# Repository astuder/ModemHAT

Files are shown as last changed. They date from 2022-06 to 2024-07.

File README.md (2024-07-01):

# Modem HAT for the Raspberry Pi

This HAT is a modem that connects the Raspberry Pi to a plain old analog telephone line.

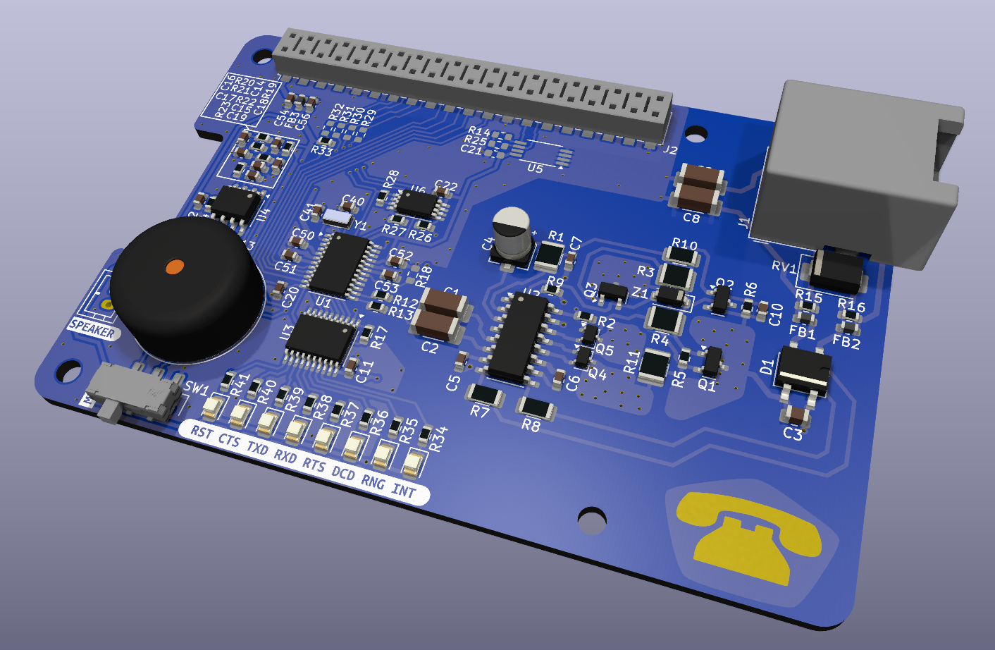
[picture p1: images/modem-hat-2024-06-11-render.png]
Render of Modem HAT


The modem presents itself to the Raspberry Pi on an UART and is controlled with the classic AT command set. It supports various standards (V.22bis, V.32bis, V.34, V.90, ...) at speeds of up to 56 kbps.

The design is based on a [Skyworks ISOmodem](https://www.skyworksinc.com/en/Products/Modems-and-DAAs/Data-and-Voice-Modems) chipset, specifically [Si2457](https://www.skyworksinc.com/en/Products/Modems-and-DAAs/Data-and-Voice-Modems/Si2457) data modem and Si3018 line side driver. The implementation
closely follows the circuits described in application note [AN93](https://www.skyworksinc.com/-/media/SkyWorks/SL/documents/public/application-notes/AN93.pdf).

The Modem HAT was successfully tested on the [Shadytel](https://shady.tel/) phone network at Toorcamp 2022.

> [!CAUTION]
> Whatever your jurisdiction, we're pretty positive that connecting this device to the public phone system IS NOT LEGAL! Don't blame us if you get into trouble.

## Raspberry Pi Configuration

> [!NOTE]
> This information was tested on Raspberry Pi 4 and Raspberry 5, running Raspberry Pi OS 12 (Bookworm). There may be differences for other versions of the Pi and/or Pi OS.

The modem HAT requires a Raspberry Pi 4 or newer.

The modem communicates through the Pi's UART on GPIO 8-11, and requires CTS and RTS for flow control. The modem supports automatic baudrate detection at speeds up to 307.2 kps.

Before first use after power-up, the modem needs to be reset. To reset the modem, GPIO25 (pin 22) is set low for at least 500ms, then set high, followed by a delay of at least 300ms. 

By default, the modem is configured for operation in the United States. For other countries the modem may have to be reconfigured after reset. See [AN93](https://www.skyworksinc.com/-/media/SkyWorks/SL/documents/public/application-notes/AN93.pdf) chapter 6.2 for details. 

Below are the configuration steps for Raspberry Pi 4 and Raspberry Pi 5.

### Raspberry Pi 4

To enable the UART, edit `/boot/firmware/config.txt` and add the following line at the end of the file:

`dtoverlay=uart4,ctsrts`

After rebooting the Raspberry Pi, the UART is mapped to `/dev/ttyAMA4`.

To reset the modem, run the Python script [`reset-pi4.py`](python/reset-pi4.py).

The modem is now ready to use. For example connect to the modem by running:

`screen /dev/ttyAMA4 115200`

Once connected to the modem, if you type `at` and press enter, the modem should respond with `OK`.

### Raspberry Pi 5

To enable the UART, edit `/boot/firmware/config.txt` and add the following line at the end of the file:

`dtoverlay=uart3-pi5,ctsrts`

After rebooting the Raspberry Pi, the UART is mapped to `/dev/ttyAMA3`.

To reset the modem, run the Python script [`reset-pi5.py`](python/reset-pi5.py).

The modem is now ready to use. For example connect to the modem by running:

`screen /dev/ttyAMA3 115200`

Once connected to the modem, if you type `at` and press enter, the modem should respond with `OK`.

## AT Command Set

The modem supports the [basic Hayes command set](https://en.wikipedia.org/wiki/Hayes_command_set#The_basic_Hayes_command_set).

For a complete list of supported AT commands as well as configuration registers refer to [AN93](https://www.skyworksinc.com/-/media/SkyWorks/SL/documents/public/application-notes/AN93.pdf) chapters 5.4 through 5.7. 

## Raspberry Pi GPIO Pinout

Required connections:
|Pin|Description|
|-|-|
|1|3.3V power for modem chipset|
|2,4|5V power for audio amplifier|
|6|GND|
|19|UART CTS|
|21|UART RX|
|22|Modem reset, RPi GPIO25|
|23|UART RTS|
|24|UART TX|

Optional connections:
|Pin|Description|
|-|-|
|13|Modem interrupt, RPi GPIO27|
|15|Modem boot config EEPROM SDIO, RPi GPIO22|
|16|Modem boot config EEPROM CS, RPi GPIO23|
|18|Modem boot config EEPROM CLK, Rpi GPIO24|
|27|RPi config EEPROM SDA|
|28|RPi config EEPROM SCL|

In the standard configuration of the HAT, the modem boot config and interrupt pins are not electrically connected to the Rasbperry Pi GPIO header. Populate R29-R32 with 0-ohm resistors to use these pins.

## Building Your Own HAT

### General

Large parts of the HAT are based on the hardware design reference in application note [AN93](https://www.skyworksinc.com/-/media/SkyWorks/SL/documents/public/application-notes/AN93.pdf) chapter 4. Where applicable, identical component designators are used to simplify cross-referencing. 

I used solder paste, stencil and reflow oven for assembly of the HAT. I also ordered partially assembled boards from JLCPCB, and manually soldered the parts that they didn't have in stock (modem chipset and high-voltage capacitors).

After soldering the through-hole parts (RJ11 connector, speaker), make sure to clip the leads on the bottom side of the HAT to avoid shorting with metal parts on the Raspberry Pi.

### Modem

The modem chipset consists of the digital part Si2457 (U1) and analog part Si3018 (U2).

These are expensive parts, costing US $13-$16 and $6-$8 respectively when purchased from reputable distributors. While tempting, beware of sources like Ebay and AliExpress as parts may be salvaged, old or even fake. It will be much easier to diagnose problems without having to second guess whether the core components of the HAT are genuine.

The HAT uses a 32.768 kHz crystal (Y1) to clock the Si2457, mainly chosen for small size and because I already had a few in my parts bin. The downside of this choice are the slow reset sequence (800 ms) and that this clocking option is only supported by Si2457 revision D (part number SI2457-D-FT) or newer.

If you suspect that you're stuck with an old part, you could try using a 4.9152 MHz crystal instead. In that case you must remove R17 which configures the clock speed. You may also have to replace the load capacitors (C40, C41) with appropriate values. See [AN93](https://www.skyworksinc.com/-/media/SkyWorks/SL/documents/public/application-notes/AN93.pdf) chapter 4.1.3 for details.

On the analog side, most of the resistors, capacitors, diodes and transistors have critical voltage, current and/or power ratings. These are all called out in the schematic. See bill of material in [AN93](https://www.skyworksinc.com/-/media/SkyWorks/SL/documents/public/application-notes/AN93.pdf) chapter 4.3 for full details. 

For bring-up and troubleshooting of the modem portion of the circuit, refer to [AN93](https://www.skyworksinc.com/-/media/SkyWorks/SL/documents/public/application-notes/AN93.pdf) chapter 10.1. 

### Audio Output / Speaker

The audio output is optional and allows monitoring of connection progress via a speaker, and who doesn't love the old-school sounds of two dial-up modems negotiating a session. It's half the reason to build this project! :)

The audio amplifier LM4819 (U4) can be substituted with the higher power, pin-compatible LM4862. Cheap, off-brand substitutes are probably fine too.

The HAT has a footprint for a 15mm speaker, like for example CUI Devices CVS-1508. Alternatively, footprint J3 provides connectivity via a JST-PH connector, or directly soldering speaker wires to the pads.

If audio is not needed, the audio amplifier (U4) and associated parts (C12-C19, R19-R24, SW1, J3) can be left unpopulated.

To enable audio output on the speaker, make sure MUTE switch is set towards the LEDs. The AT command to enable speaker output while dialing and handshaking is `ATM1`. Speaker volume is controlled with `ATL1` through `ATL4`, where 4 is the loudest.

### Modem Boot Config EEPROM

The modem boot config EEPROM is optional and can store AT commands that the modem automatically runs after reset. See [AN93](https://www.skyworksinc.com/-/media/SkyWorks/SL/documents/public/application-notes/AN93.pdf) chapter 2.7 for details.

The EEPROM can be programmed by the modem with AT commands. For hacking, the EEPROM can also be connected to the Raspberry Pi by populating R29, R30 and R31. For the latter, keep the modem in reset while interacting with the EEPROM.

If this functionality is not needed, the EEPROM (U6) and associated parts (C22, R26, R27, R28) can be left unpopulated.

### Raspberry Pi HAT ID EEPROM

The HAT ID EEPROM is optional and can store information that allows the Raspberry Pi to recognize the HAT and load the required device tree overlay, i.e. automatically configure UART and other pins.

I haven't figured out the content for this EEPROM yet. Specification is [here](https://github.com/raspberrypi/hats/blob/master/eeprom-format.md). Contributions are welcome :)

If this functionality is not needed, the EEPROM (U5) and associated parts (C21, R14, R25) can be left unpopulated.

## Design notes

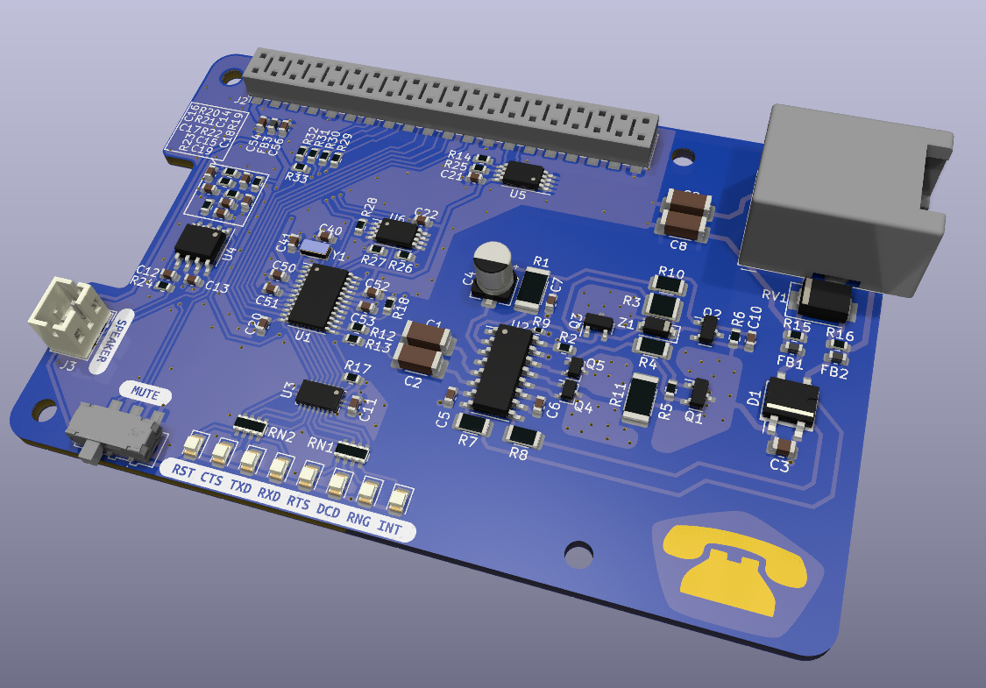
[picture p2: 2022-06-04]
images/modem-hat-2022-05-08-render.png

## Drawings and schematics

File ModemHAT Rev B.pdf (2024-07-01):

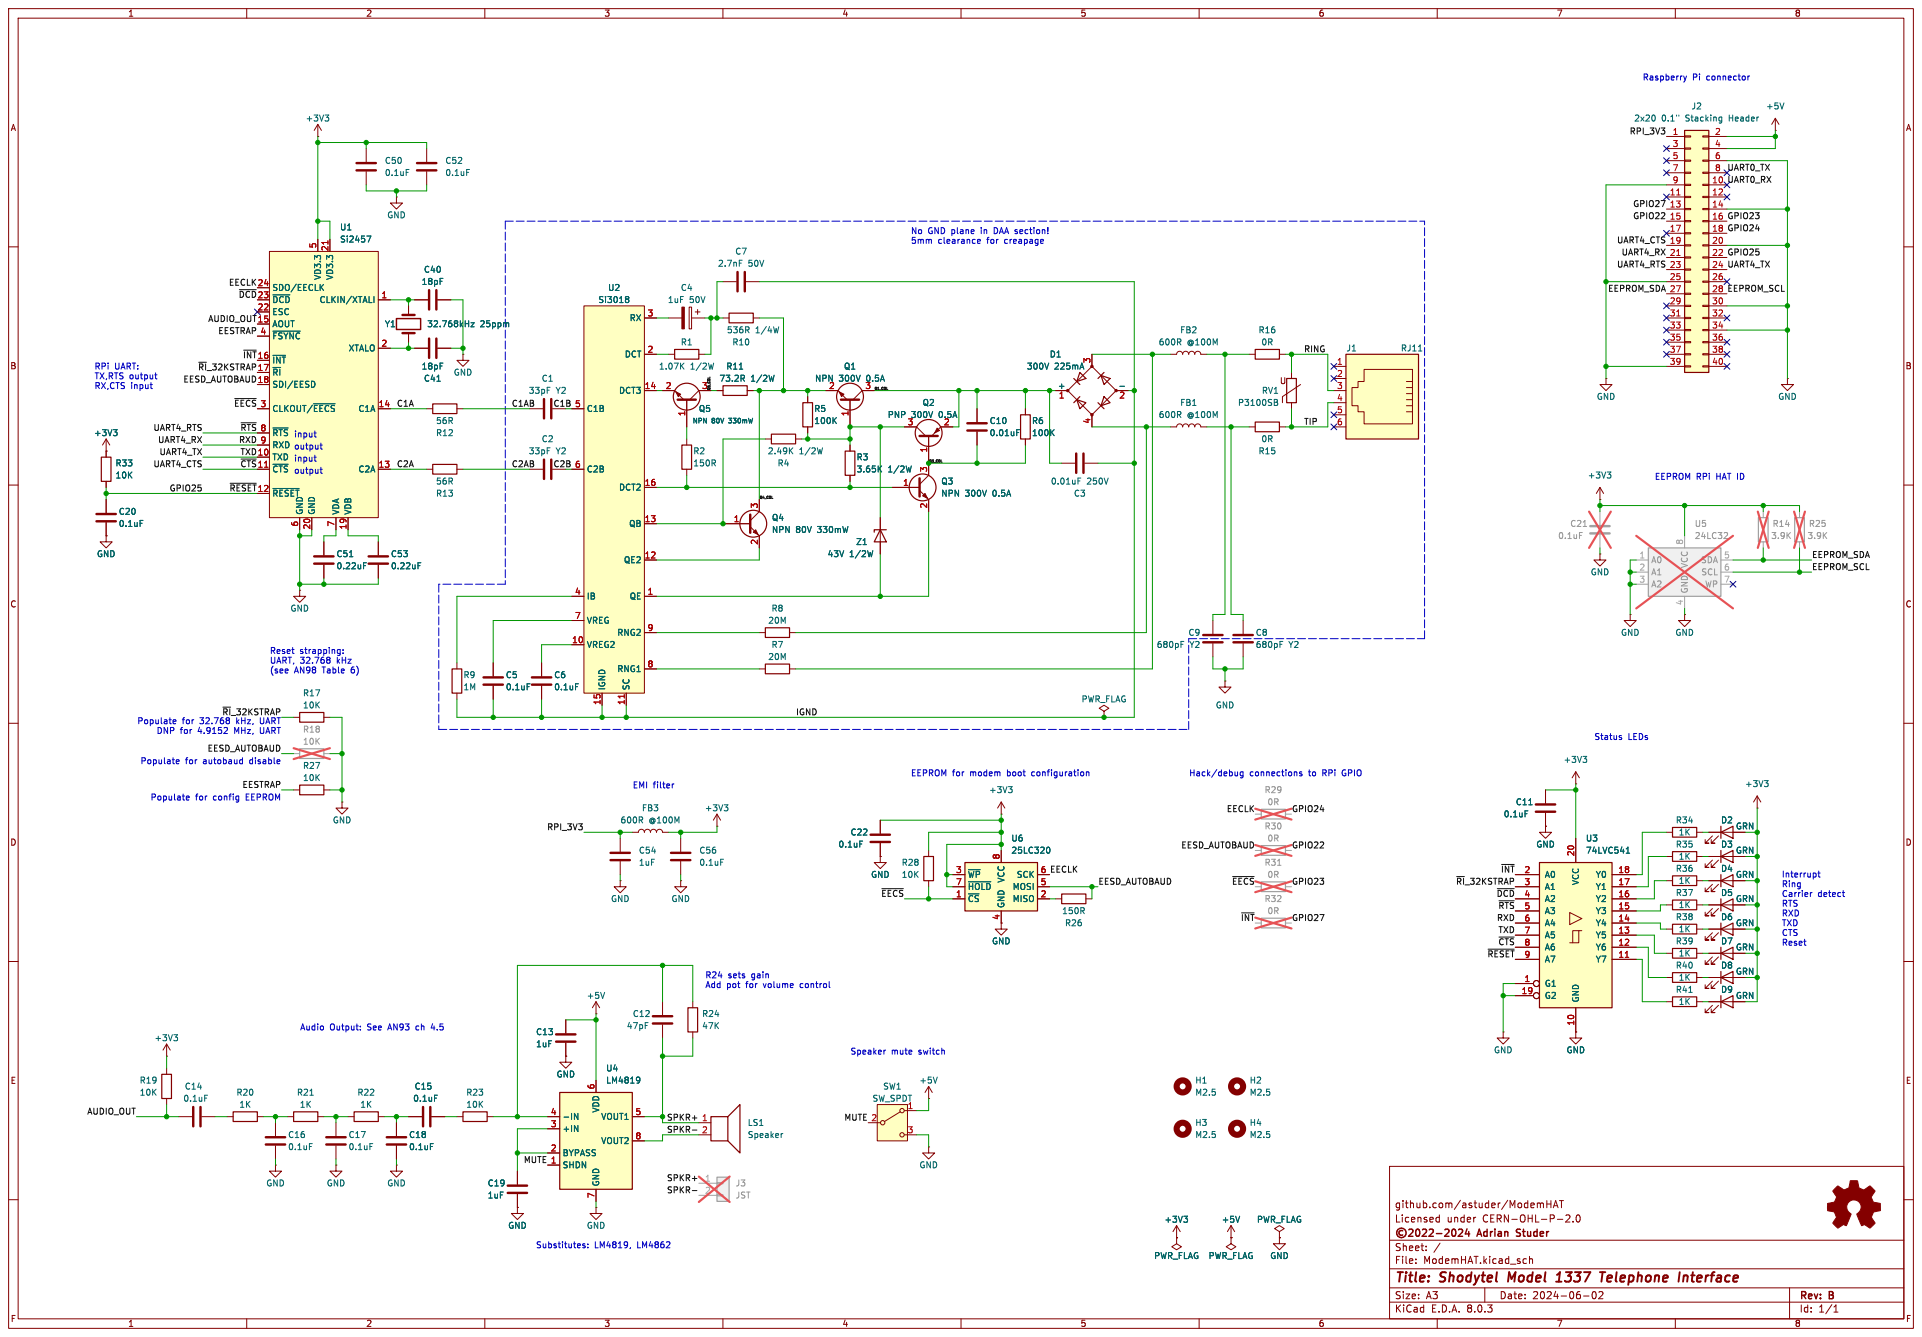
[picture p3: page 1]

Reset strapping: UART, 32.768 kHz

4 MOSI 5 SCK 6 ~{HOLD} 7 VCC

Interrupt
Ring Carrier detect RTS RXD

R24 sets gain Add pot for volume control

github.com/astuder/ModemHAT

Id: 1/1 Title: Shodytel Model 1337 Telephone Interface

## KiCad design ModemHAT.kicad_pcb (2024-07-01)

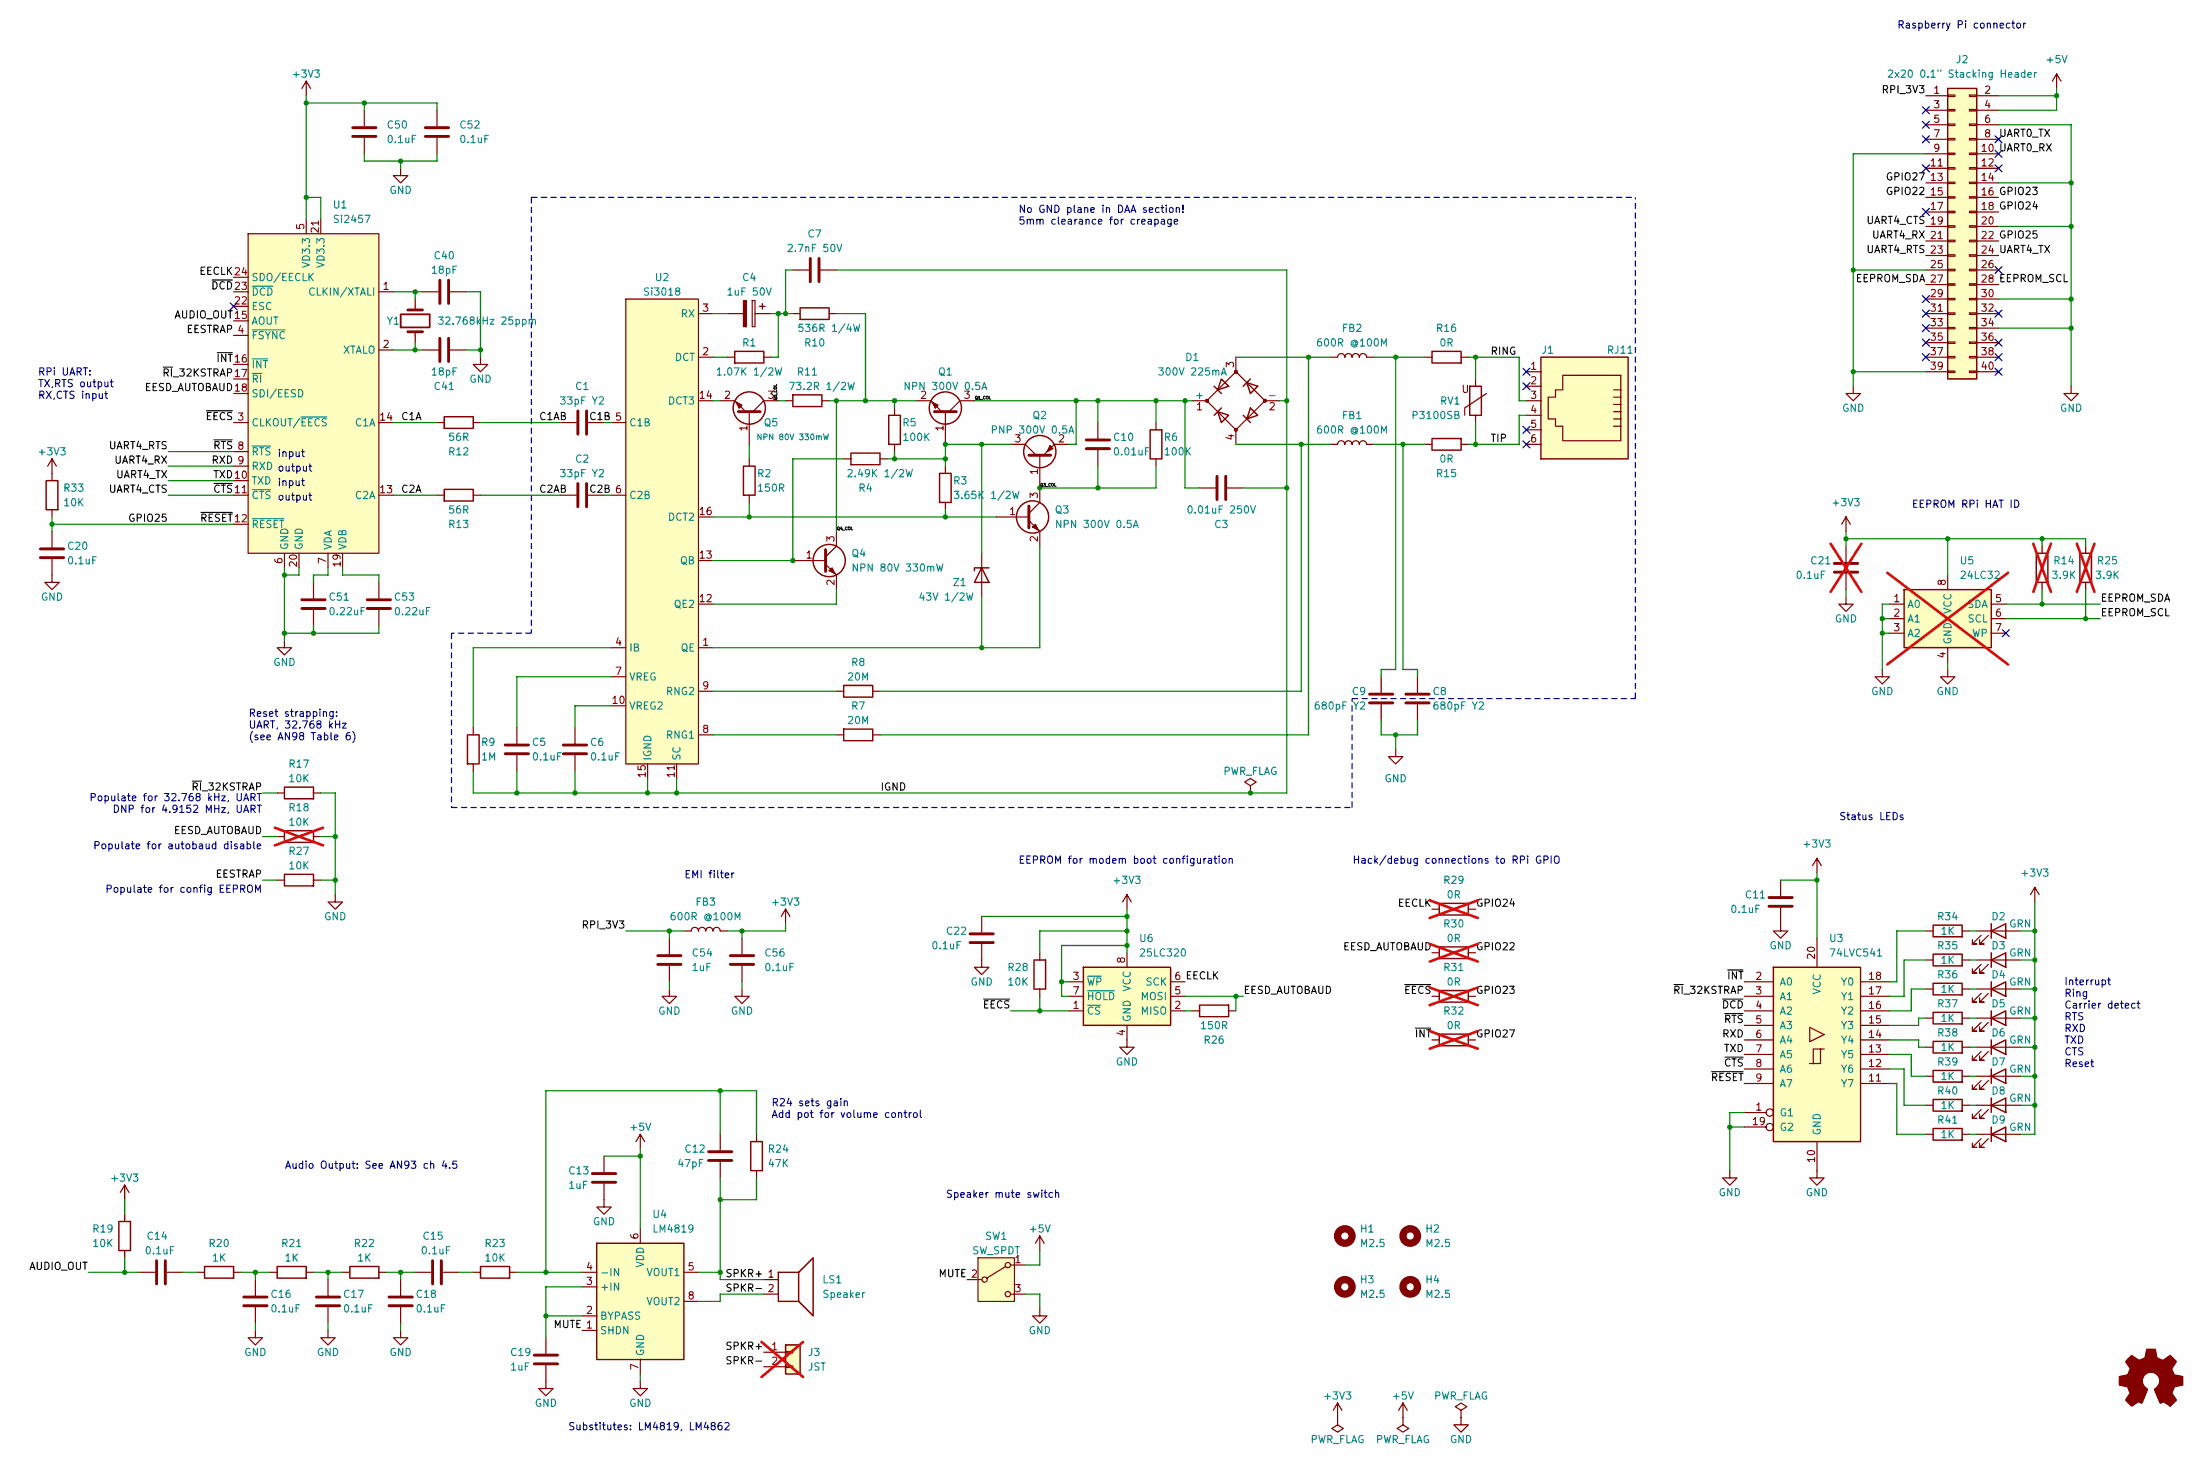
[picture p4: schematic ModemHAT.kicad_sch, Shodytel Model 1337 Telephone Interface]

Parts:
C1, C2: 33pF Y2; C_1808_4520Metric; MPN SCC1808N330J502TG
C3: 0.01uF 250V; C_0805_2012Metric; MPN GRM21BR72E103KW03L
C4: 1uF 50V; CP_Elec_4x5.4; LCSC C371267
C5, C6, C11, C14, C15, C16, C17, C18, C20, C22, C50, C52, C56: 0.1uF; C_0603_1608Metric; LCSC C14663
C7: 2.7nF 50V; C_0603_1608Metric; LCSC C1609
C8, C9: 680pF Y2; C_1808_4520Metric; MPN 502R29W681KV3E-****-SC
C10: 0.01uF; C_0603_1608Metric; LCSC C57112
C12: 47pF; C_0603_1608Metric; LCSC C1671
C13, C19, C54: 1uF; C_0603_1608Metric; LCSC C15849
C21: 0.1uF; C_0603_1608Metric; LCSC C14663; not fitted
C40, C41: 18pF; C_0603_1608Metric; LCSC C1647
C51, C53: 0.22uF; C_0603_1608Metric; LCSC C21120
D1: 300V 225mA; TO-269AA-R; MPN MB4S-TP; LCSC C151727
D2, D3, D4, D5, D6, D7, D8, D9: GRN; LED_0805_2012Metric; LCSC C2297
FB1, FB2, FB3: 600R @100M; L_0603_1608Metric; MPN BLM18AG601SN1D; LCSC C1002
H1, H2, H3, H4: M2.5; MountingHole_2.7mm_M2.5
J1: RJ11; RJ12_Amphenol_54601-x06_Horizontal; MPN 54601-906001WPLF
J2: 2x20 0.1" Stacking Header; Raspberry_Pi_Stacking_Header; LCSC C2685112
J3: JST; JST_PH_B2B-PH-K_1x02_P2.00mm_Vertical; not fitted
LS1: Speaker; Buzzer_15x7.5RM7.6; MPN CVS-1508
Q1, Q3: NPN 300V 0.5A; SOT-23; MPN MMBTA42; LCSC C20069138
Q2: PNP 300V 0.5A; SOT-23; MPN MMBTA92; LCSC C20069146
Q4, Q5: NPN 80V 330mW; SOT-323_SC-70; MPN MMBTA06W; LCSC C268584
R1: 1.07K 1/2W; R_1210_3225Metric; LCSC C333114
R2, R26: 150R; R_0603_1608Metric; LCSC C22808
R3: 3.65K 1/2W; R_1210_3225Metric; LCSC C230230
R4: 2.49K 1/2W; R_1210_3225Metric; LCSC C705453
R5, R6: 100K; R_0603_1608Metric; LCSC C25803
R7, R8: 20M; R_1206_3216Metric; LCSC C384452
R9: 1M; R_0603_1608Metric; LCSC C22935
R10: 536R 1/4W; R_1206_3216Metric; LCSC C364152
R11: 73.2R 1/2W; R_1210_3225Metric; LCSC C2991291
R12, R13: 56R; R_0603_1608Metric; LCSC C25196
R14, R25: 3.9K; R_0603_1608Metric; LCSC C23018; not fitted
R15, R16: 0R; R_0603_1608Metric; LCSC C21189
R17, R19, R23, R27, R28, R33: 10K; R_0603_1608Metric; LCSC C25804
R18: 10K; R_0603_1608Metric; LCSC C25804; not fitted
R20, R21, R22, R34, R35, R36, R37, R38, R39, R40, R41: 1K; R_0603_1608Metric; LCSC C21190
R24: 47K; R_0603_1608Metric; LCSC C25819
R29, R30, R31, R32: 0R; R_0603_1608Metric; LCSC C25819; not fitted
RV1: P3100SB; D_SMB; MPN P3100SBLRP; LCSC C3012560
SW1: SW_SPDT; SW_SPDT_CK_JS102011SAQN; MPN JS102011SAQN; LCSC C221660
U1: Si2457; TSSOP-24_4.4x7.8mm_P0.65mm; MPN Si2457-D-FT
U2: Si3018; SOIC-16_3.9x9.9mm_P1.27mm; MPN Si3018-F-GS
U3: 74LVC541; TSSOP-20_4.4x6.5mm_P0.65mm; LCSC C5657
U4: LM4819; SOIC-8_3.9x4.9mm_P1.27mm; MPN LM4819MX/NOPB; LCSC C87265
U5: 24LC32; TSSOP-8_4.4x3mm_P0.65mm; MPN CAT24C32YI-GT3; not fitted
U6: 25LC320; TSSOP-8_4.4x3mm_P0.65mm; MPN 25LC320AT-I/ST; LCSC C2061659
Y1: 32.768kHz 25ppm; Crystal_SMD_3215-2Pin_3.2x1.5mm; MPN ECS-.327-12.5-34B-TR; LCSC C32346
Z1: 43V 1/2W; D_SOD-123; MPN MMSZ5260BT1G; LCSC C6909653

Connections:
+3V3: C11.1, C21.1, C22.1, C50.2, C52.2, C56.2, D2.2 (A), D3.2 (A), D4.2 (A), D5.2 (A), D6.2 (A), D7.2 (A), D8.2 (A), D9.2 (A), FB3.2, R14.1, R19.2, R25.1, R28.2, R33.1, U1.5 (VD3.3), U1.21 (VD3.3), U3.20 (VCC), U5.8 (VCC), U6.3 (~WP), U6.7 (~HOLD), U6.8 (VCC)
+5V: C13.2, J2.2, J2.4, SW1.1 (A), U4.6 (VDD)
/AUDIO_OUT: C14.2, R19.1, U1.15 (AOUT)
/C1A: R12.2, U1.14 (C1A)
/C1AB: C1.1, R12.1
/C1B: C1.2, U2.5 (C1B)
/C2A: R13.2, U1.13 (C2A)
/C2AB: C2.1, R13.1
/C2B: C2.2, U2.6 (C2B)
/EECLK: R29.2, U1.24 (SDO/EECLK), U6.6 (SCK)
/EEPROM_SCL: J2.28, R25.2, U5.6 (SCL)
/EEPROM_SDA: J2.27, R14.2, U5.5 (SDA)
/EESD_AUTOBAUD: R18.1, R26.2, R30.2, U1.18 (SDI/EESD), U6.5 (MOSI)
/EESTRAP: R27.1, U1.4 (~FSYNC)
/GPIO22: J2.15, R30.1
/GPIO23: J2.16, R31.1
/GPIO24: J2.18, R29.1
/GPIO25: C20.2, J2.22, R33.2, U1.12 (~RESET), U3.9 (A7)
/GPIO27: J2.13, R32.1
/IGND: C3.1, C5.2, C6.2, C7.1, D1.2 (-), R9.2, U2.11 (SC), U2.15 (IGND)
/MUTE: SW1.2 (B), U4.1 (SHDN)
/Q1_COL: C3.2, C10.2, D1.1 (+), Q1.3 (C), Q2.2 (E), R6.2
/Q3_COL: C10.1, Q2.1 (B), Q3.3 (C), R6.1
/Q4_COL: Q1.2 (E), Q4.3 (C), R5.1, R10.1, R11.1
/Q5_COL: Q5.3 (C), R11.2
/RING: J1.3, R16.2, RV1.2
/RPI_3V3: C54.2, FB3.1, J2.1
/RXD: J2.21, U1.9 (RXD), U3.6 (A4)
/SPKR+: C12.2, J3.1, LS1.1, R24.2, U4.5 (VOUT1)
/SPKR-: J3.2, LS1.2, U4.8 (VOUT2)
/TIP: J1.4, R15.2, RV1.1
/TXD: J2.24, U1.10 (TXD), U3.7 (A5)
/UART0_RX: J2.10
/UART0_TX: J2.8
/UART4_CTS: J2.19, U1.11 (~CTS), U3.8 (A6)
/UART4_RTS: J2.23, U1.8 (~RTS), U3.5 (A3)
/~DCD: U1.23 (~DCD), U3.4 (A2)
/~EECS: R28.1, R31.2, U1.3 (CLKOUT/~EECS), U6.1 (~CS)
/~INT: R32.2, U1.16 (~INT), U3.2 (A0)
/~RI_32KSTRAP: R17.1, U1.17 (~RI), U3.3 (A1)
GND: C8.2, C9.2, C11.2, C13.1, C16.1, C17.1, C18.1, C19.1, C20.1, C21.2, C22.2, C40.2, C41.2, C50.1, C51.2, C52.1, C53.2, C54.1, C56.1, J2.6, J2.9, J2.14, J2.20, J2.25, J2.30, J2.34, J2.39, R17.2, R18.2, R27.2, SW1.3 (C), U1.6 (GND), U1.20 (GND), U3.1 (G1), U3.10 (GND), U3.19 (G2), U4.7 (GND), U5.1 (A0), U5.2 (A1), U5.3 (A2), U5.4 (GND), U6.4 (GND)
unnamed: C4.1, C7.2, R1.1, R10.2
unnamed: C8.1, FB1.2, R15.1
unnamed: C9.1, FB2.2, R16.1
unnamed: C14.1, R20.1
unnamed: C15.1, R23.1
unnamed: C15.2, C18.2, R22.2
unnamed: C16.2, R20.2, R21.1
unnamed: C17.2, R21.2, R22.1
unnamed: D1.3, FB2.1, R7.1
unnamed: D1.4, FB1.1, R8.1
unnamed: D2.1 (K), R34.2
unnamed: D3.1 (K), R35.2
unnamed: D4.1 (K), R36.2
unnamed: D5.1 (K), R37.2
unnamed: D6.1 (K), R38.2
unnamed: D7.1 (K), R39.2
unnamed: D8.1 (K), R40.2
unnamed: D9.1 (K), R41.2
unnamed: Q1.1 (B), Q2.3 (C), R3.1, R4.1, R5.2, Z1.1 (K)
unnamed: Q3.1 (B), R2.2, R3.2, U2.16 (DCT2)
unnamed: Q3.2 (E), U2.1 (QE), Z1.2 (A)
unnamed: Q4.1 (B), R4.2, U2.13 (QB)
unnamed: Q4.2 (E), U2.12 (QE2)
unnamed: Q5.1 (B), R2.1
unnamed: Q5.2 (E), U2.14 (DCT3)
unnamed: C40.1, U1.1 (CLKIN/XTALI), Y1.2
unnamed: C51.1, U1.7 (VDA)
unnamed: C53.1, U1.19 (VDB)
unnamed: C41.1, U1.2 (XTALO), Y1.1
unnamed: R1.2, U2.2 (DCT)
unnamed: R9.1, U2.4 (IB)
unnamed: R7.2, U2.8 (RNG1)
unnamed: R8.2, U2.9 (RNG2)
unnamed: C4.2, U2.3 (RX)
unnamed: C6.1, U2.10 (VREG2)
unnamed: C5.1, U2.7 (VREG)
unnamed: R34.1, U3.18 (Y0)
unnamed: R35.1, U3.17 (Y1)
unnamed: R36.1, U3.16 (Y2)
unnamed: R37.1, U3.15 (Y3)
unnamed: R38.1, U3.14 (Y4)
unnamed: R39.1, U3.13 (Y5)
unnamed: R40.1, U3.12 (Y6)
unnamed: R41.1, U3.11 (Y7)
unnamed: C19.2, U4.2 (BYPASS), U4.3 (+IN)
unnamed: C12.1, R23.2, R24.1, U4.4 (-IN)
unnamed: R26.1, U6.2 (MISO)

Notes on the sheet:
Audio Output: See AN93 ch 4.5
Reset strapping: UART, 32.768 kHz (see AN98 Table 6)
EEPROM for modem boot configuration
output
Populate for autobaud disable
EMI filter
Interrupt Ring Carrier detect RTS RXD TXD CTS Reset
EEPROM RPi HAT ID
Status LEDs
Populate for 32.768 kHz, UART DNP for 4.9152 MHz, UART
Speaker mute switch
No GND plane in DAA section! 5mm clearance for creapage
Hack/debug connections to RPi GPIO
Populate for config EEPROM
Raspberry Pi connector
R24 sets gain Add pot for volume control
input
Substitutes: LM4819, LM4862
RPi UART: TX,RTS output RX,CTS input

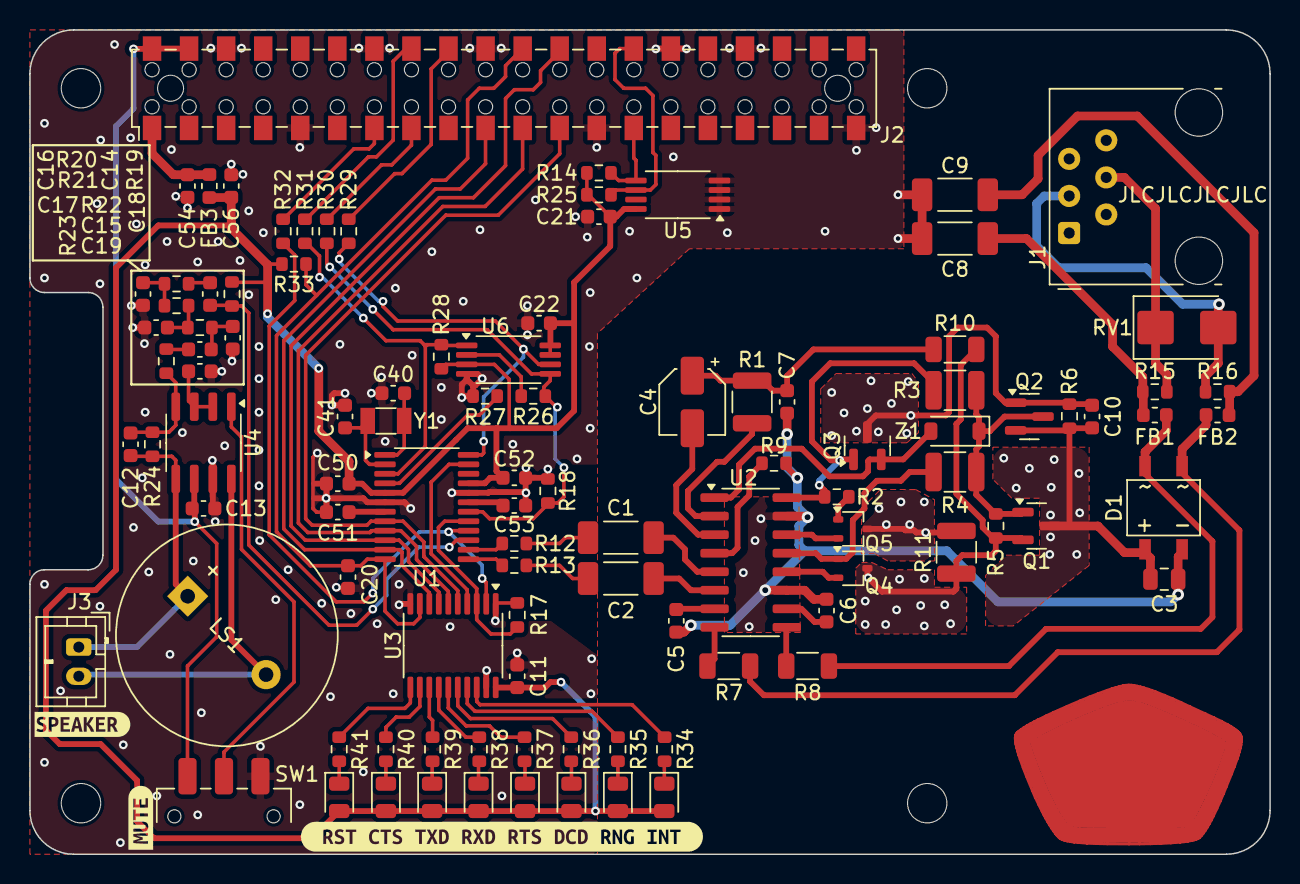
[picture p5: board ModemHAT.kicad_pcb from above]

Board: 2 copper layers, 85.0 x 56.5 mm, 109 parts (0 on the bottom side), 86 nets.

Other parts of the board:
kibuzzard-665D11B2: G***; kibuzzard-665D11B2
kibuzzard-665D1212: G***; kibuzzard-665D1212
kibuzzard-62720846: G***; kibuzzard-62720846

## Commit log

2022-06-04 move trace away from mounting hole
    [ModemHAT.kicad_pcb]
2022-06-04 move vias
    [ModemHAT.kicad_pcb]
2022-06-04 added more mfg part numbers
    [ModemHAT.kicad_pcb, ModemHAT.kicad_sch]
2022-06-05 audio circuit comments
    [ModemHAT.kicad_sch]
2022-07-28 minor PCB edits, report successful field test
    [ModemHAT.kicad_pcb]
2024-06-12 rev B
    [ModemHAT.kicad_pcb, ModemHAT.kicad_sch]
2024-07-01 add schematic PDF
    [ModemHAT.kicad_pcb, ModemHAT.kicad_sch]

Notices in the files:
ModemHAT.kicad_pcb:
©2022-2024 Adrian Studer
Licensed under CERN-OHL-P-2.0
